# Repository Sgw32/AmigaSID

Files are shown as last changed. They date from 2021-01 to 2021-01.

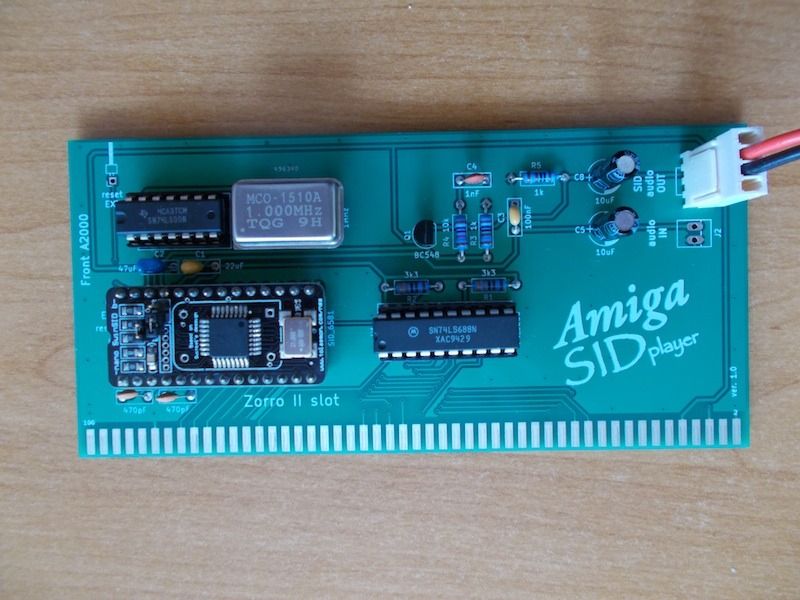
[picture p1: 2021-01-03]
original/3.jpg

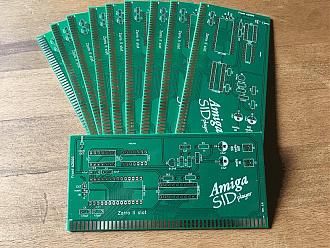
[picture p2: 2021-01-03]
original/1.jpg

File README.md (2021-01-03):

# AmigaSID - A2000 version is main

Amiga SID Zorro II card

Use at your own risk!!!

Project forked from: 
http://www.amibay.com/showthread.php?108629-Amiga-SID-player-for-Zorro-slot

Player: http://aminet.net/package/misc/emu/FrodoV2_4

Videos:
https://www.youtube.com/watch?app=desktop&v=QOlyukb5uWo
https://www.youtube.com/watch?v=6BfD3O8DvEo

Project information in "original" folder

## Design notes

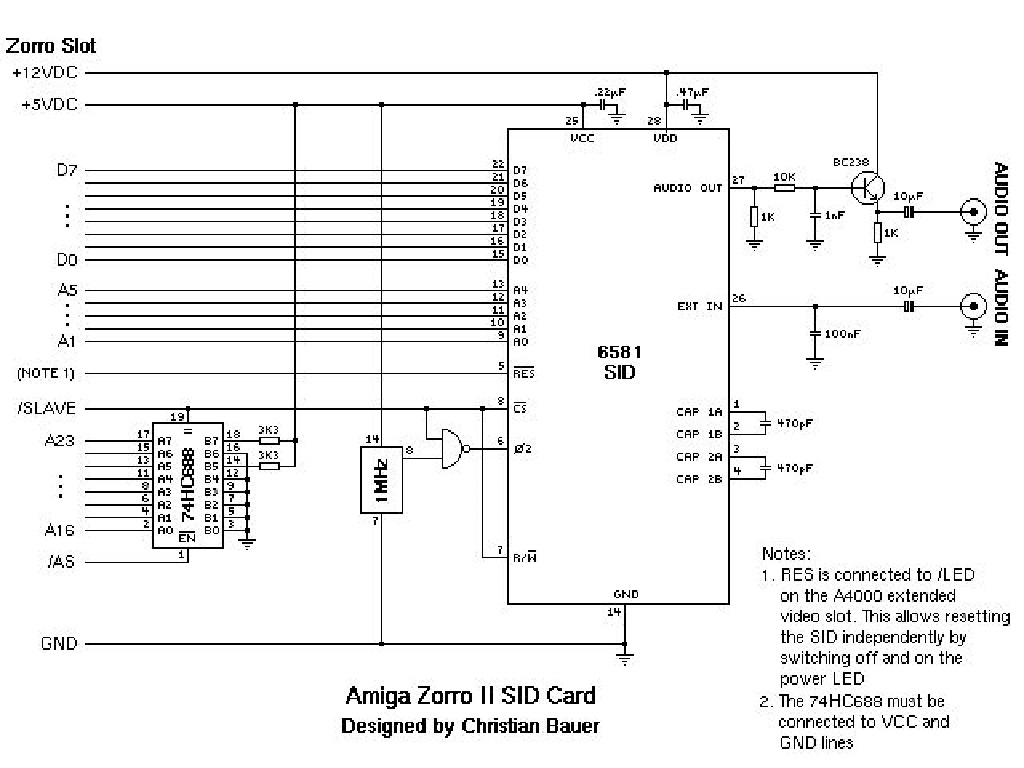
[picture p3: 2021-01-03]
original/schematic.jpg

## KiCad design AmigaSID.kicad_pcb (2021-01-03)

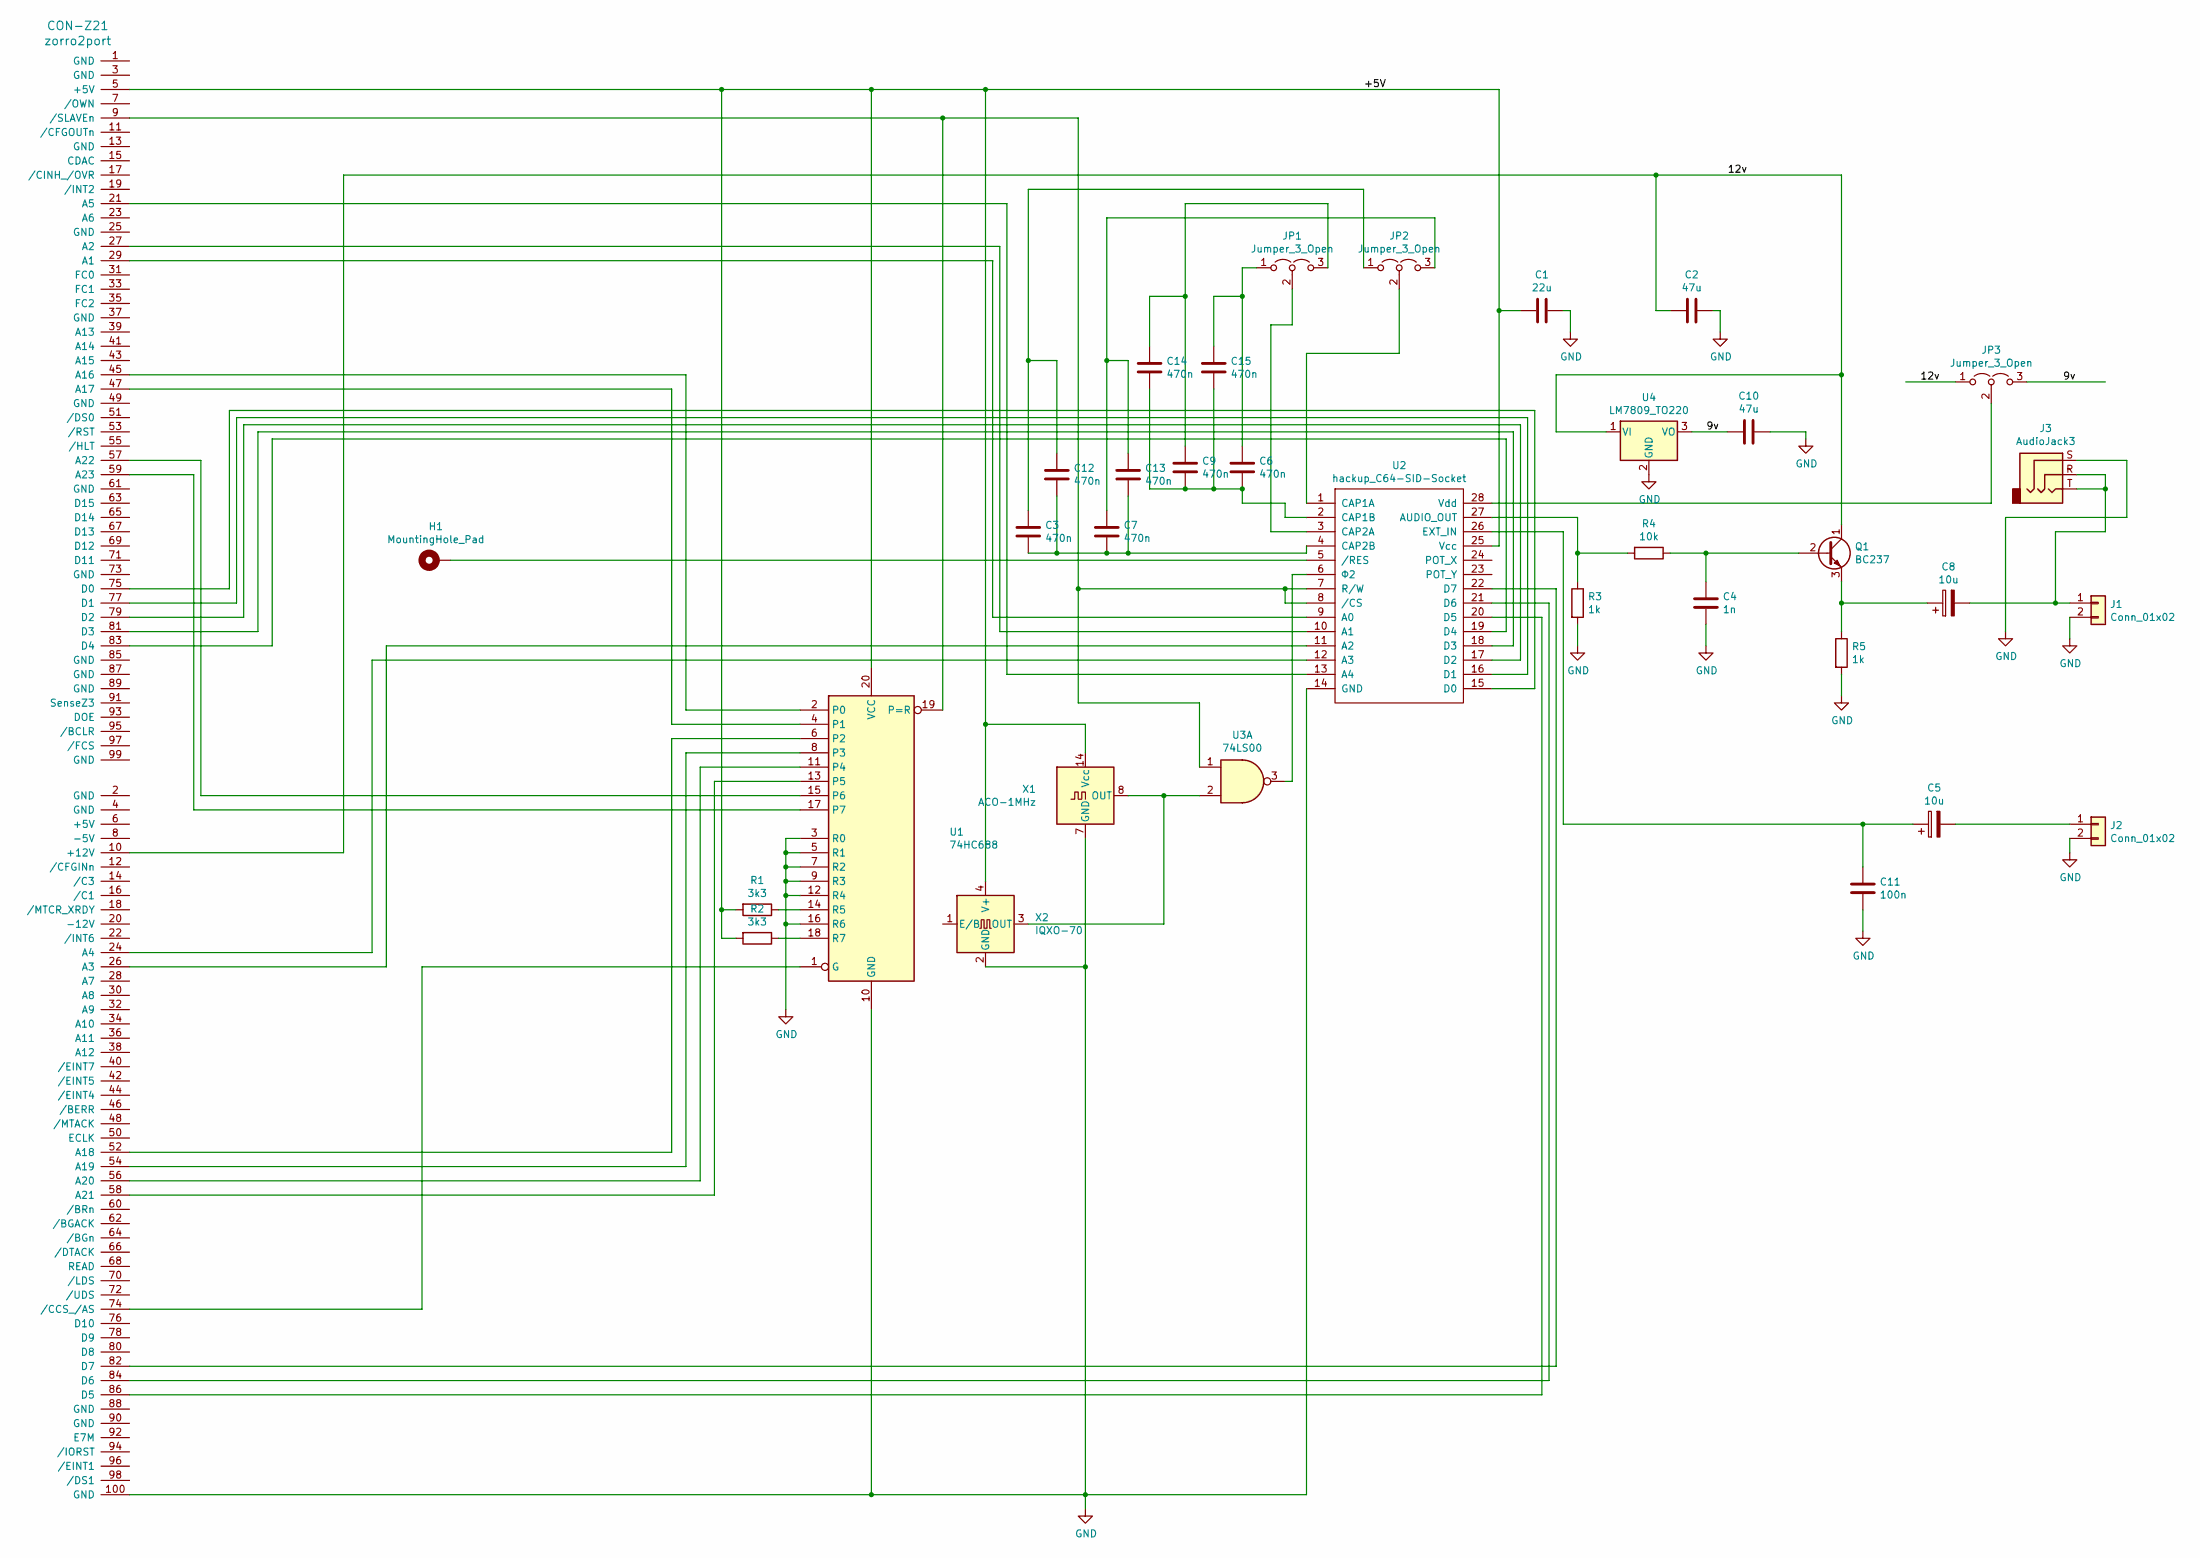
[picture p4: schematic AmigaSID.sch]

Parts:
C1: 22u; C_Disc_D4.7mm_W2.5mm_P5.00mm
C2, C10: 47u; C_Disc_D4.7mm_W2.5mm_P5.00mm
C3, C6, C7, C9: 470n; C_Disc_D4.7mm_W2.5mm_P5.00mm
C4: 1n; C_Disc_D4.7mm_W2.5mm_P5.00mm
C5, C8: 10u; CP_Radial_D7.5mm_P2.50mm
C11: 100n; C_Disc_D4.7mm_W2.5mm_P5.00mm
C12, C13, C14, C15: 470n; C_0805_2012Metric
CON-Z21: zorro2port; zorro2card
H1: MountingHole_Pad; Pin_D0.7mm_L6.5mm_W1.8mm_FlatFork
J1, J2: Conn_01x02; TerminalBlock_4Ucon_1x02_P3.50mm_Horizontal
J3: AudioJack3; Jack_3.5mm_CUI_SJ1-3533NG_Horizontal_CircularHoles
JP1, JP2, JP3: Jumper_3_Open; PinHeader_1x03_P2.54mm_Vertical
Q1: BC237; TO-92_Inline
R1, R2: 3k3; R_Axial_DIN0207_L6.3mm_D2.5mm_P10.16mm_Horizontal
R3, R5: 1k; R_Axial_DIN0207_L6.3mm_D2.5mm_P10.16mm_Horizontal
R4: 10k; R_Axial_DIN0207_L6.3mm_D2.5mm_P10.16mm_Horizontal
U1: 74HC688; DIP-20_W7.62mm_Socket_LongPads
U2: hackup_C64-SID-Socket; DIP-28_W15.24mm_Socket_LongPads
U3: 74LS00; DIP-14_W7.62mm_Socket_LongPads
U4: LM7809_TO220; TO-220-3_Vertical
X1: ACO-1MHz; Oscillator_DIP-14
X2: IQXO-70; Oscillator_SMD_IQD_IQXO70-4Pin_7.5x5.0mm

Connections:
/9v: C10.2, JP3.3 (B), U4.3 (VO)
/12v: C2.2, CON-Z21.10 (+12V), JP3.1 (A), Q1.1 (C), U4.1 (VI)
/+5V: C1.2, CON-Z21.5 (+5V), R1.2, R2.2, U1.20 (VCC), U2.25 (Vcc), X1.14 (Vcc), X2.4 (V+)
GND: C1.1, C2.1, C4.2, C10.1, C11.2, CON-Z21.100 (GND), J1.2, J2.2, J3.S, R3.2, R5.2, U1.3 (R0), U1.5 (R1), U1.7 (R2), U1.9 (R3), U1.10 (GND), U1.12 (R4), U1.16 (R6), U2.14 (GND), U4.2 (GND), X1.7 (GND), X2.2 (GND)
unnamed: C4.1, Q1.2 (B), R4.1
unnamed: C5.2, J2.1
unnamed: C8.1, Q1.3 (E), R5.1
unnamed: C8.2, J1.1, J3.R, J3.T
unnamed: C5.1, C11.1, U2.26 (EXT_IN)
unnamed: C3.1, C12.1, JP2.1 (A)
unnamed: C3.2, C7.2, C12.2, C13.2, U2.4 (CAP2B)
unnamed: C7.1, C13.1, JP2.3 (B)
unnamed: C9.1, C14.1, JP1.3 (B)
unnamed: C6.2, C9.2, C14.2, C15.2, U2.2 (CAP1B)
unnamed: C6.1, C15.1, JP1.1 (A)
unnamed: CON-Z21.9 (/SLAVEn), U1.19 (P=R), U2.7 (R/W), U2.8 (/CS), U3.1
unnamed: CON-Z21.21 (A5), U2.13 (A4)
unnamed: CON-Z21.24 (A4), U2.12 (A3)
unnamed: CON-Z21.26 (A3), U2.11 (A2)
unnamed: CON-Z21.27 (A2), U2.10 (A1)
unnamed: CON-Z21.29 (A1), U2.9 (A0)
unnamed: CON-Z21.45 (A16), U1.2 (P0)
unnamed: CON-Z21.47 (A17), U1.4 (P1)
unnamed: CON-Z21.52 (A18), U1.6 (P2)
unnamed: CON-Z21.54 (A19), U1.8 (P3)
unnamed: CON-Z21.56 (A20), U1.11 (P4)
unnamed: CON-Z21.57 (A22), U1.15 (P6)
unnamed: CON-Z21.58 (A21), U1.13 (P5)
unnamed: CON-Z21.59 (A23), U1.17 (P7)
unnamed: CON-Z21.74 (/CCS_/AS), U1.1 (G)
unnamed: CON-Z21.75 (D0), U2.15 (D0)
unnamed: CON-Z21.77 (D1), U2.16 (D1)
unnamed: CON-Z21.79 (D2), U2.17 (D2)
unnamed: CON-Z21.81 (D3), U2.18 (D3)
unnamed: CON-Z21.82 (D7), U2.22 (D7)
unnamed: CON-Z21.83 (D4), U2.19 (D4)
unnamed: CON-Z21.84 (D6), U2.21 (D6)
unnamed: CON-Z21.86 (D5), U2.20 (D5)
unnamed: H1.1, U2.5 (/RES)
unnamed: JP1.2 (C), U2.3 (CAP2A)
unnamed: JP2.2 (C), U2.1 (CAP1A)
unnamed: JP3.2 (C), U2.28 (Vdd)
unnamed: R1.1, U1.14 (R5)
unnamed: R2.1, U1.18 (R7)
unnamed: R3.1, R4.2, U2.27 (AUDIO_OUT)
unnamed: U2.6 (Φ2), U3.3
unnamed: U3.2, X1.8 (OUT), X2.3 (OUT)

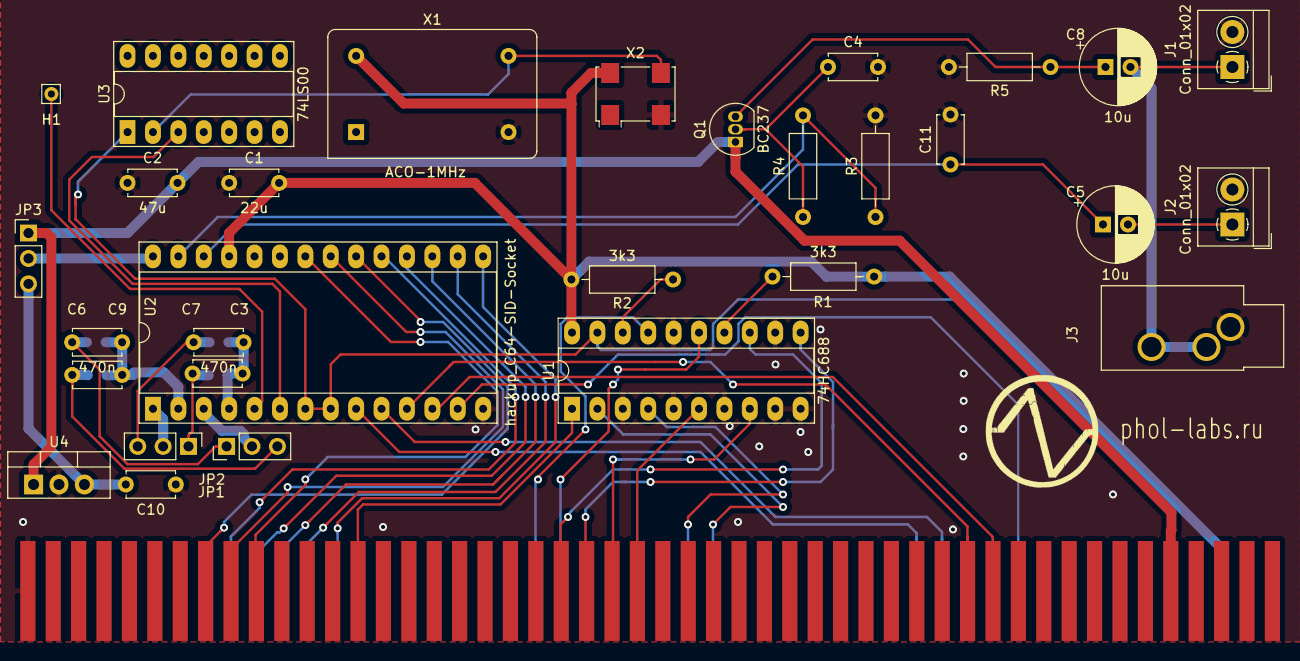
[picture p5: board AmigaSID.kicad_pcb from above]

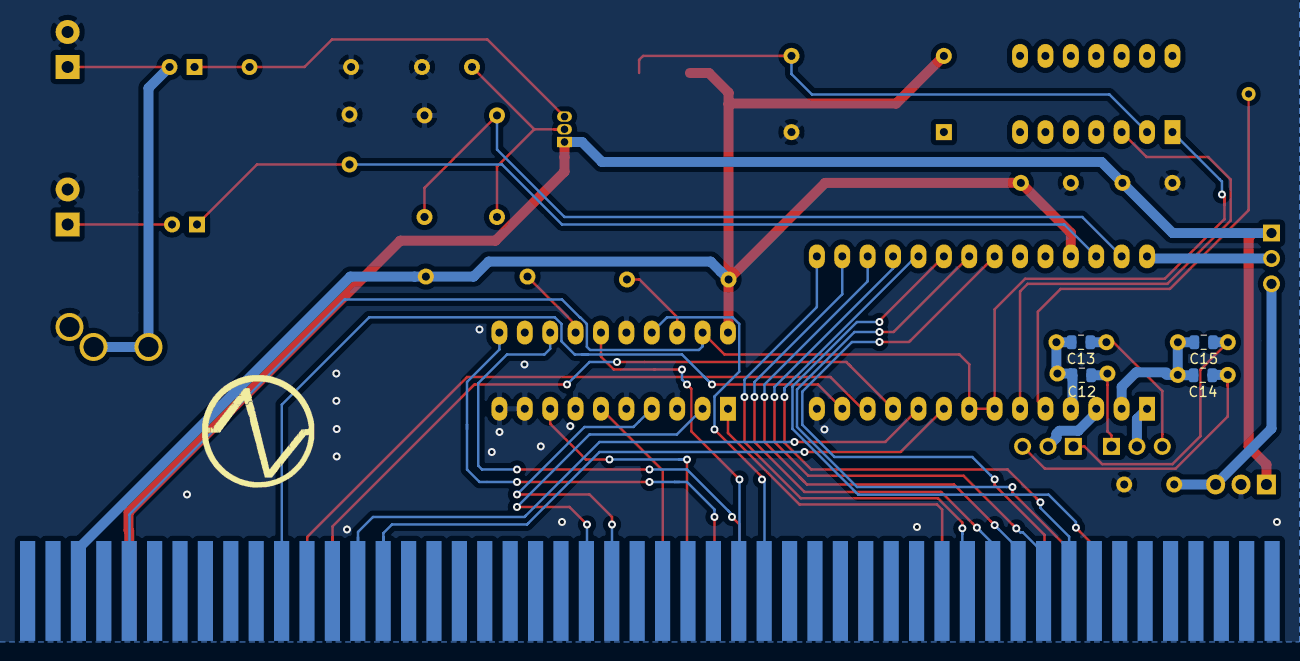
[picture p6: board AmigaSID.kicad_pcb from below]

Board: 2 copper layers, 35 parts (4 on the bottom side), 47 nets.
